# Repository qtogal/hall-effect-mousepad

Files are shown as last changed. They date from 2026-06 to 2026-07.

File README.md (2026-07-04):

Readme for the halleffectmousepad project.

This project aims to create a mousepad that includes a grid of hall effect sensors to detect magnets. The values of each will be interpreted by a program to calculate the position of the magnet even if it is not on the exact position of a sensor. 

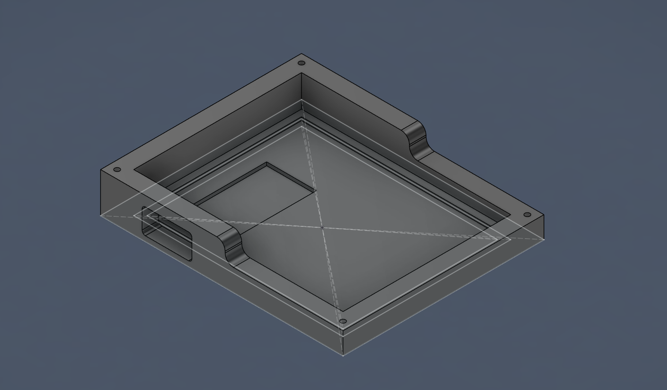
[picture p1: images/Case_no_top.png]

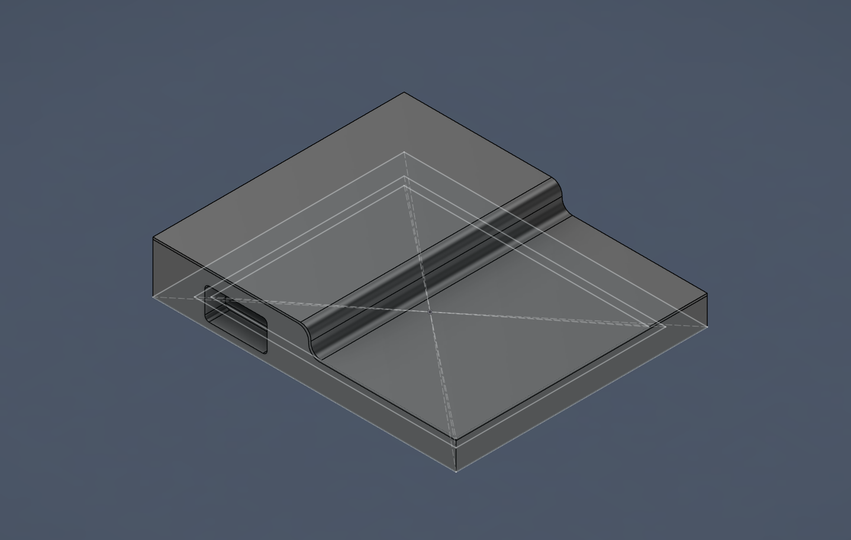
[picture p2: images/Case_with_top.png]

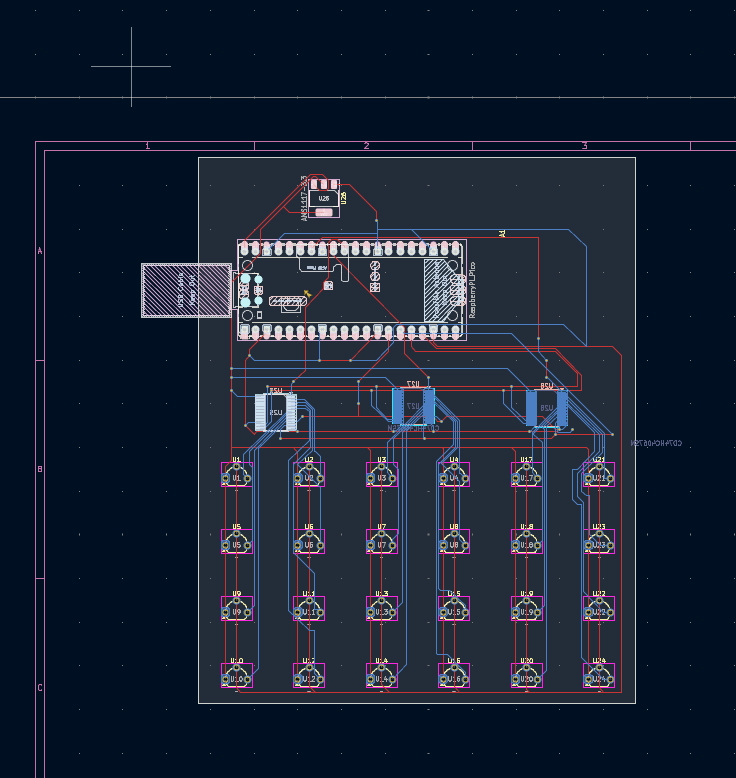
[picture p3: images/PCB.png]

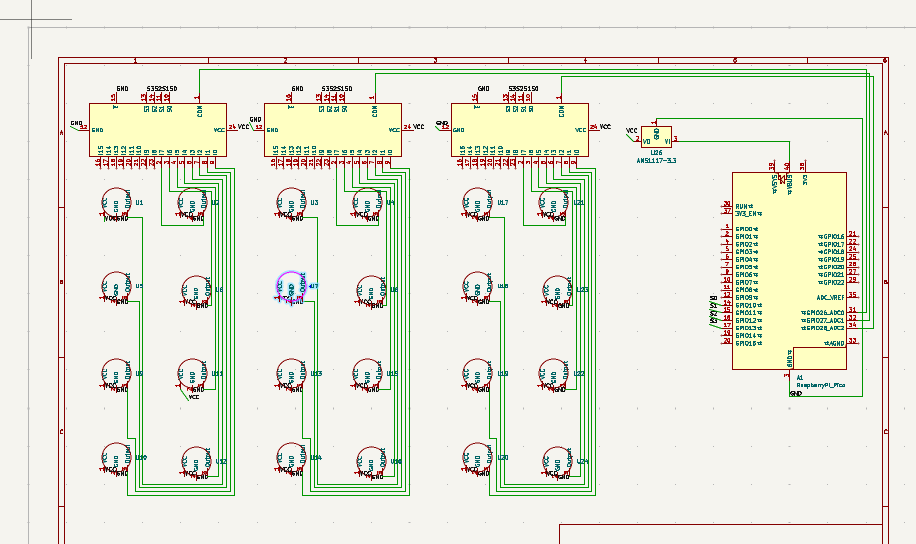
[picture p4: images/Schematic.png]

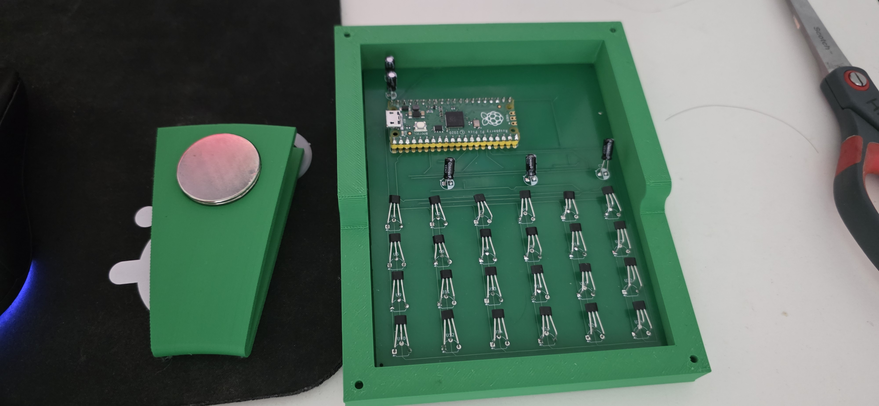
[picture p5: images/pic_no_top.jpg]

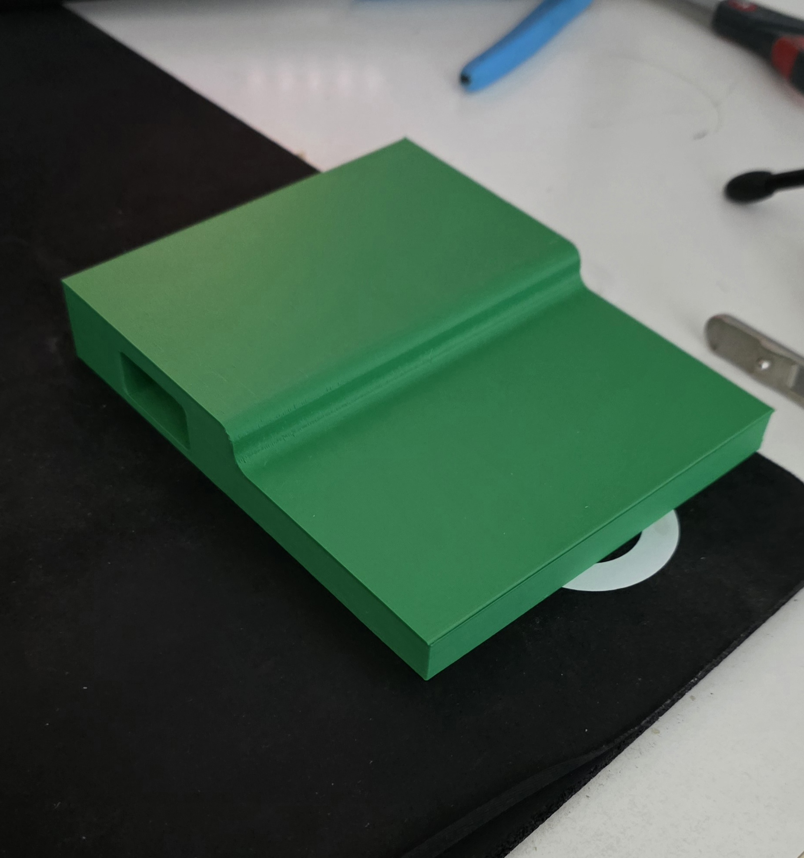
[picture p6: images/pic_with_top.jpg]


# BOM
 |Part|QTY|
 |---|---|
 |SS49E Hall Effect Sensor|24|
 |CD74HC4067SE analog mux|3|
 |AMS1117-3.3 regulator|1|
 |Neodyum magnets 12mm diameter*2mm|1|
 |0.1 uF capacitor|3|
 |10uF capacitor|2|
 |3D printed case|1|
 |3D printed magnet casing|1|
 |usb cable|1|

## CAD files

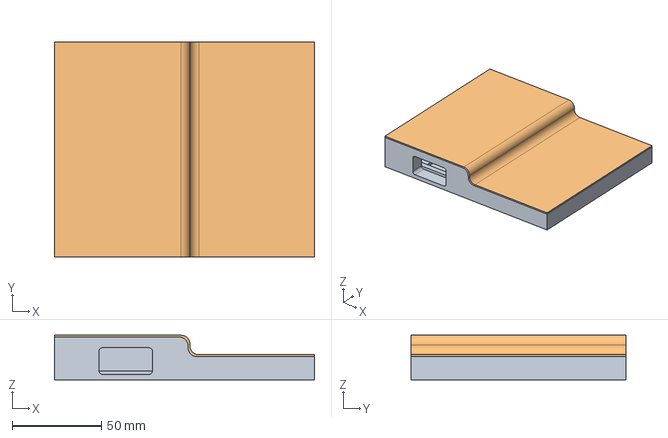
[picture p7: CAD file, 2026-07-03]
CAD/mousepad_.step
146.0 x 121.0 x 25.0 mm
コンポーネント1
コンポーネント3

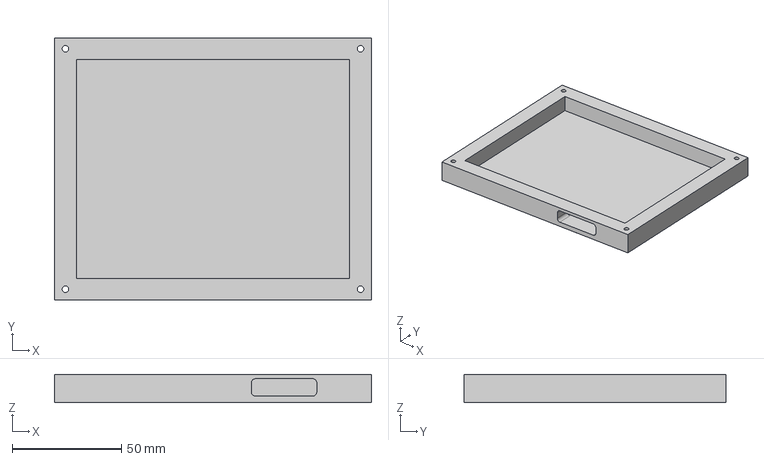
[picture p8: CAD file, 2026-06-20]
Production/Bottom.step
145.0 x 120.0 x 13.0 mm

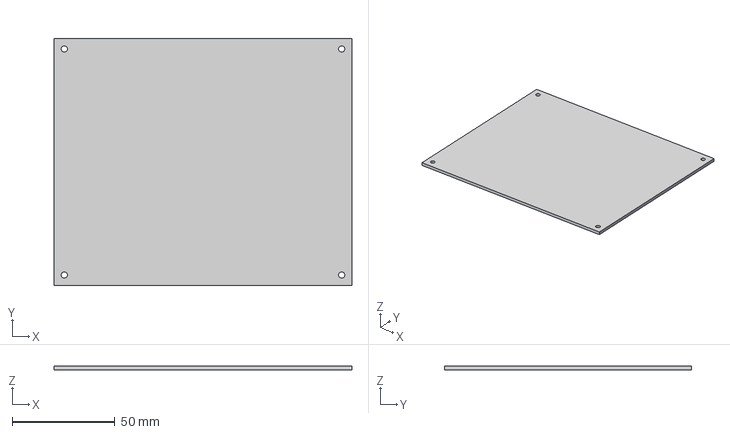
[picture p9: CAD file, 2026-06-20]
Production/top.step
145.0 x 120.0 x 2.00 mm

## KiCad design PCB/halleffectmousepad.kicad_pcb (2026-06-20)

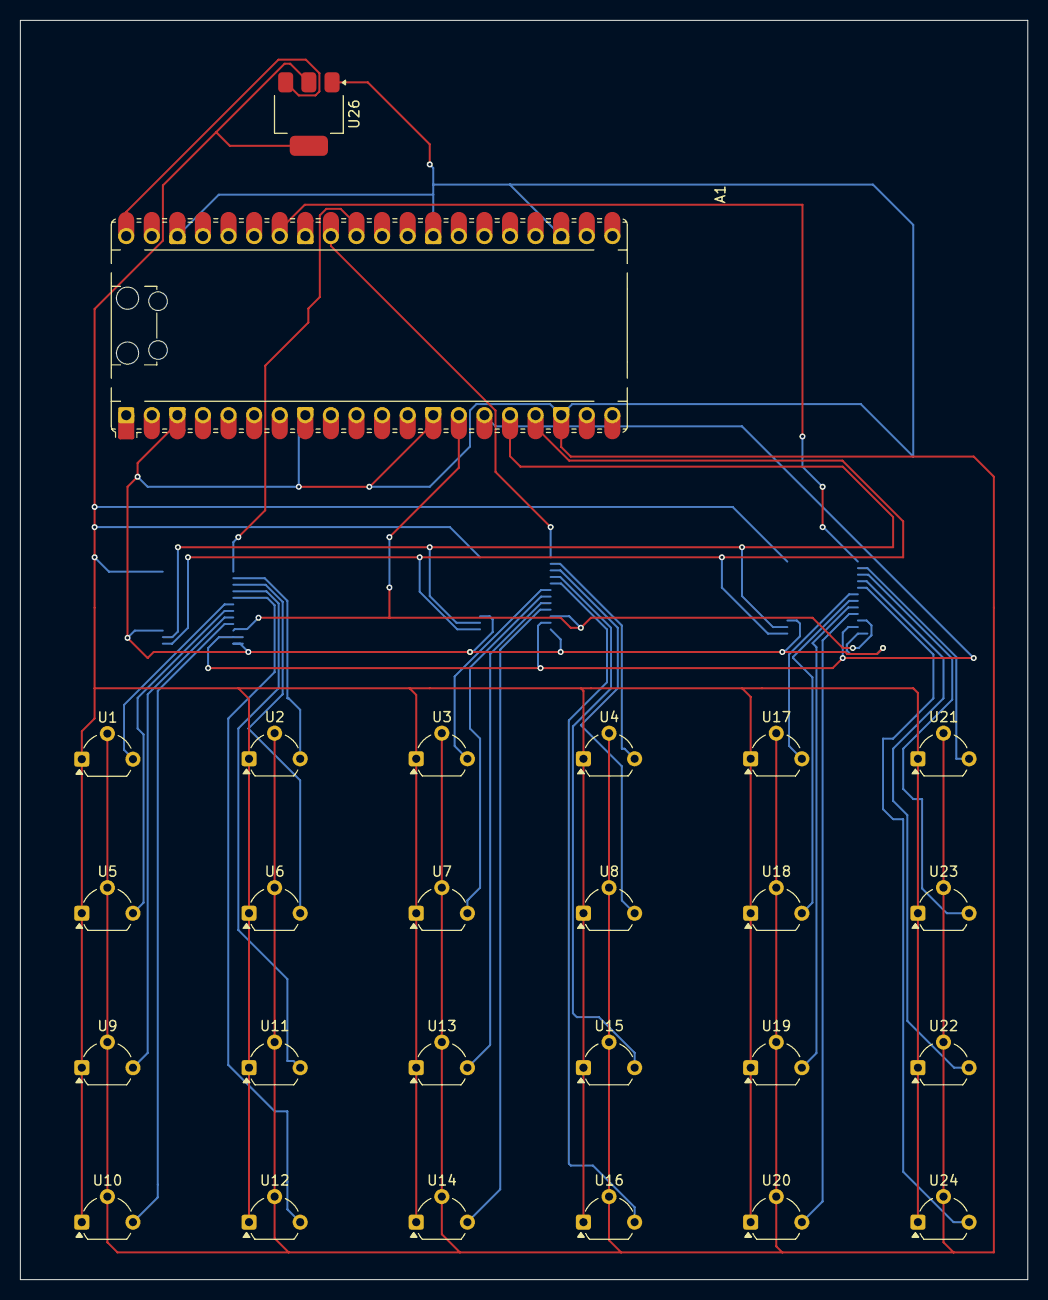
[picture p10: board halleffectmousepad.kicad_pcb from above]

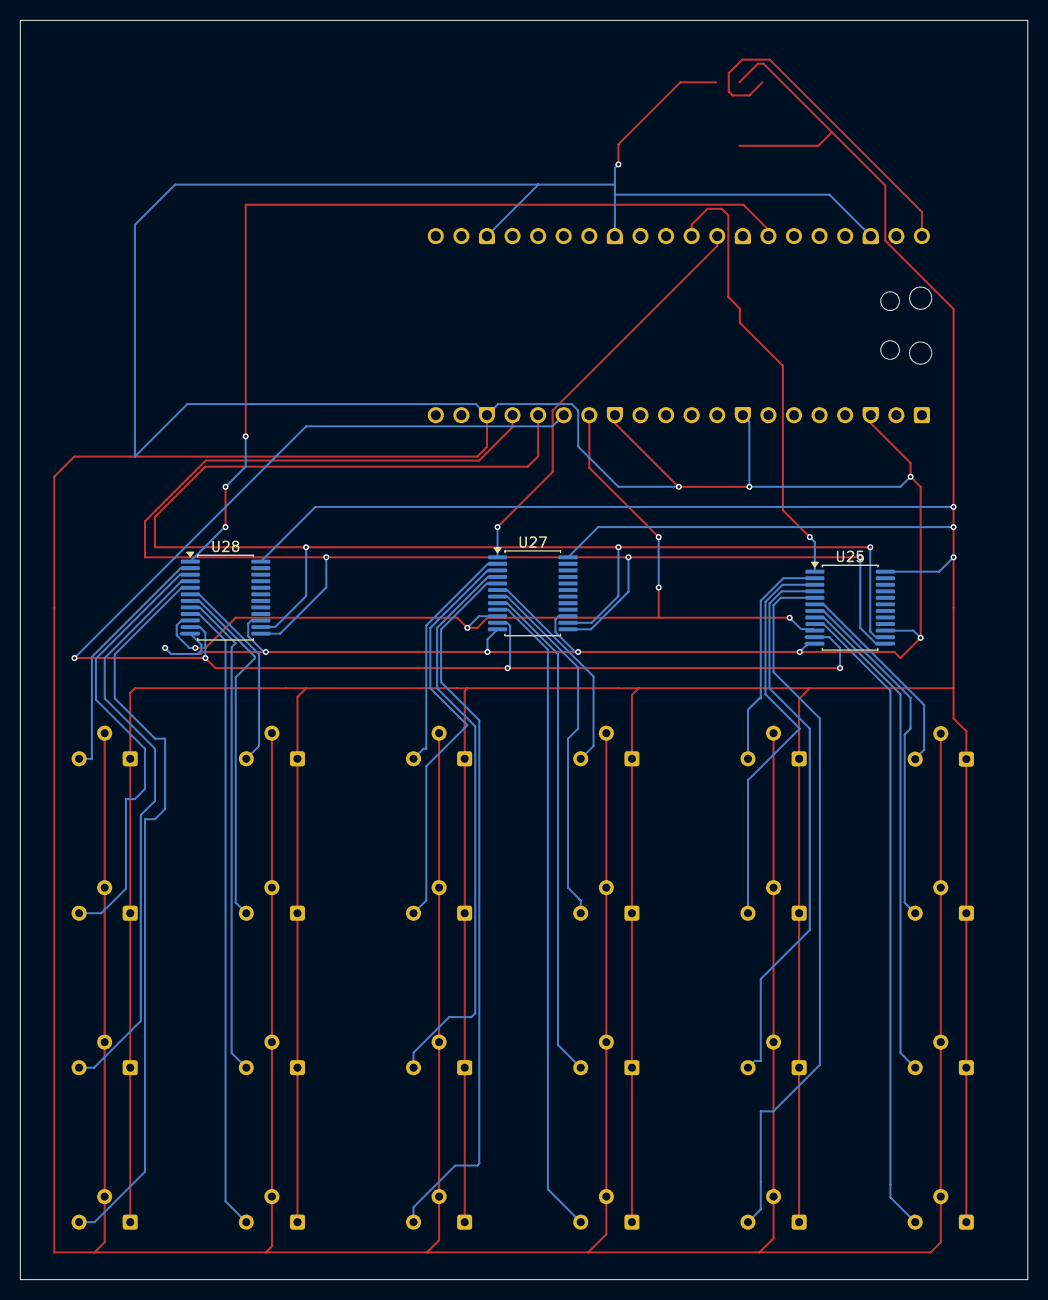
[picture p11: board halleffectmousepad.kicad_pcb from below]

Board: 2 copper layers, 100.0 x 125.0 mm, 29 parts (3 on the bottom side), 34 nets.

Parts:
A1: RaspberryPi_Pico; RaspberryPi_Pico_Common_Unspecified
U1, U2, U3, U4, U5, U6, U7, U8, U9, U10, U11, U12, U13, U14, U15, U16, U17, U18, U19, U20, U21, U22, U23, U24: TO-92L_Wide
U25, U27, U28: CD74HC4067SM; SSOP-24_5.3x8.2mm_P0.65mm
U26: AMS1117-3.3; SOT-223-3_TabPin2

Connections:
/GND: A1.3 (GND), A1.8 (GND), A1.13 (GND), A1.18 (GND), A1.23 (GND), A1.28 (GND), A1.38 (GND), U1.2 (GND), U2.2 (GND), U3.2 (GND), U4.2 (GND), U5.2 (GND), U6.2 (GND), U7.2 (GND), U8.2 (GND), U9.2 (GND), U10.2 (GND), U11.2 (GND), U12.2 (GND), U13.2 (GND), U14.2 (GND), U15.2 (GND), U16.2 (GND), U17.2 (GND), U18.2 (GND), U19.2 (GND), U20.2 (GND), U21.2 (GND), U22.2 (GND), U23.2 (GND), U24.2 (GND), U25.12 (GND), U25.15 (~E), U26.1 (GND), U27.12 (GND), U27.15 (~E), U28.12 (GND), U28.15 (~E)
/S0: A1.14 (GPIO10), U25.10 (S0), U27.10 (S0), U28.10 (S0)
/S1: A1.15 (GPIO11), U25.11 (S1), U27.11 (S1), U28.11 (S1)
/S2: A1.16 (GPIO12), U25.14 (S2), U27.14 (S2), U28.14 (S2)
/S3: A1.17 (GPIO13), U25.13 (S3), U27.13 (S3), U28.13 (S3)
/VCC: U1.1 (VCC), U2.1 (VCC), U3.1 (VCC), U4.1 (VCC), U5.1 (VCC), U6.1 (VCC), U7.1 (VCC), U8.1 (VCC), U9.1 (VCC), U10.1 (VCC), U11.1 (VCC), U12.1 (VCC), U13.1 (VCC), U14.1 (VCC), U15.1 (VCC), U16.1 (VCC), U17.1 (VCC), U18.1 (VCC), U19.1 (VCC), U20.1 (VCC), U21.1 (VCC), U22.1 (VCC), U23.1 (VCC), U24.1 (VCC), U25.24 (VCC), U26.2 (VO), U27.24 (VCC), U28.24 (VCC)
unnamed: A1.31 (GPIO26_ADC0), U25.1 (COM)
unnamed: A1.32 (GPIO27_ADC1), U27.1 (COM)
unnamed: A1.34 (GPIO28_ADC2), U28.1 (COM)
unnamed: A1.40 (VBUS), U26.3 (VI)
unnamed: U1.3 (Output), U25.6 (I3)
unnamed: U2.3 (Output), U25.2 (I7)
unnamed: U10.3 (Output), U25.9 (I0)
unnamed: U11.3 (Output), U25.4 (I5)
unnamed: U12.3 (Output), U25.5 (I4)
unnamed: U13.3 (Output), U27.8 (I1)
unnamed: U14.3 (Output), U27.9 (I0)
unnamed: U15.3 (Output), U27.4 (I5)
unnamed: U16.3 (Output), U27.5 (I4)
unnamed: U17.3 (Output), U28.6 (I3)
unnamed: U18.3 (Output), U28.7 (I2)
unnamed: U19.3 (Output), U28.8 (I1)
unnamed: U20.3 (Output), U28.9 (I0)
unnamed: U21.3 (Output), U28.2 (I7)
unnamed: U22.3 (Output), U28.4 (I5)
unnamed: U23.3 (Output), U28.3 (I6)
unnamed: U24.3 (Output), U28.5 (I4)
unnamed: U9.3 (Output), U25.8 (I1)
unnamed: U5.3 (Output), U25.7 (I2)
unnamed: U6.3 (Output), U25.3 (I6)
unnamed: U7.3 (Output), U27.7 (I2)
unnamed: U3.3 (Output), U27.6 (I3)
unnamed: U8.3 (Output), U27.3 (I6)
unnamed: U4.3 (Output), U27.2 (I7)

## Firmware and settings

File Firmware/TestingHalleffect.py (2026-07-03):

import time
import board
import analogio
import digitalio
import usb_hid
from adafruit_hid.mouse import Mouse

COLS = 6
ROWS = 4
MUX = 3
row_spacing = 16.6
col_spacing = 15.3

N = COLS*ROWS

select = []

for i in (board.GP10, board.GP11, board.GP12, board.GP13):
    pin = digitalio.DigitalInOut(i)
    pin.direction = digitalio.Direction.OUTPUT
    select.append(pin)

adc = [
    analogio.AnalogIn(board.A0),
    analogio.AnalogIn(board.A1),
    analogio.AnalogIn(board.A2),
]

mouse = Mouse(usb_hid.devices)

#Make the mapping of the sensor layout based on the pins connected to each sensor, (ch, x, y)
mux0_sensor_map = [
    (0,0,3), (1,0,2), (2,0,1), (3,0,0), (4,1,3), (5,1,2), (6,1,1), (7,1,0)
]

mux1_sensor_map = [
    (0,2,3), (1,2,2), (2,2,1), (3,2,0), (4,3,3), (5,3,2), (6,3,1), (7,3,0)
]

mux2_sensor_map = [
    (0,4,3), (1,4,2), (2,4,1), (3,4,0), (4,5,3), (5,5,2), (6,5,1), (7,5,0)
]

mux_map = [mux0_sensor_map, mux1_sensor_map, mux2_sensor_map]

sensor_map = [
    [0,0,0,0,0,0,0,0],
    [0,0,0,0,0,0,0,0],
    [0,0,0,0,0,0,0,0],          
]

baseline_sensor = sensor_map

using_map = [
    [0,0,0,0,0,0,0,0],
    [0,0,0,0,0,0,0,0],
    [0,0,0,0,0,0,0,0],          
]

def set_channel(ch):
    for i, pin in enumerate(select):
        pin.value = bool((ch >>i )&1)

def read_all():
    for i in range(8):
        set_channel(i)
        sensor_map[mux0_sensor_map[i][2]][mux0_sensor_map[i][1]] = abs(adc[mux0_sensor_map[i][0]].value)
        sensor_map[mux1_sensor_map[i][2]][mux1_sensor_map[i][1]] = abs(adc[mux1_sensor_map[i][0]].value)
        sensor_map[mux2_sensor_map[i][2]][mux2_sensor_map[i][1]] = abs(adc[mux2_sensor_map[i][0]].value)
    
#actual code for mouse detection

#constants
noise = 300                             # per sensor adc count jitter range
lift = 3000                             # adc value maximum before considering lifted
dpi = 20                                # scaling movement distance
wait = 0.001                            # delay set for mux to settle
calibration_frames = 20                 # initial sensor calibration frames
smooth = 0.5                            # fraction of change in x and y recorded as movement
delay = 0.25
click_ratio = 1.5

# Calibrate sensor readings by taking an average over 20 frames

for _ in range(calibration_frames):
    read_all()
    for i in range(MUX):
        for j in range(N/MUX):
            baseline_sensor[i][j] += sensor_map[i][j]
    
for i in range(MUX):
    for j in range(N/MUX):
        baseline_sensor[i][j]/calibration_frames

prev_cx = None       # previous frame position
prev_cy = None
smooth_cx = None     # low-pass-filtered cursor position
smooth_cy = None
rem_x = 0.0          # carry sub-pixel remainders
rem_y = 0.0
click_top_threshold = 5000    # click when reading a value above this
click_bot_threshold = 4000    # unclick when reading a value below this
clicking = False     # if button is pressed
settle_until = 0.0   # clicks don't activate until this time after the magnet lands

while True:
    now = time.monotonic()
    sx = 0.0
    sy = 0.0
    total = 0
    peak = 0

    read_all()
    for i in range(MUX):
        for j in range(N/MUX):
            w = sensor_map[i][j] - baseline_sensor[i][j]
            if w>noise:
                x = mux_map[i][j][2]
                y = mux_map[i][j][3]
                sx += w*x
                sy += w*y
                total += w
                if w> peak: 
                    peak = w
    if total > LIFT:   #weighted average
        cx = sx/total
        cy = sy/total
        if smooth_cx is None:  #record cx and cy as smooth_cx and smooth_cy if they don't have any values stored
            smooth_cx = cx
            smooth_cy = cy
        else:
            smooth_cx += (cx - smooth_cx)*smooth
            smooth_cy += (cy - smooth_cy)*smooth
        if prev_cx is None:   #No previous position is recorded
            prev_cx = smooth_cx
            prev_cy = smooth_cy
            rem_x = 0.0
            rem_y = 0.0
        else:
            dx = (smooth_cx - prev_cx)*dpi + rem_x
            dy = (smooth_cy - prev_cy)*dpi + rem_y
            ix = int(dx)
            iy = int(dy)
            rem_x = dx - ix
            rem_y = dy - iy
            if ix != 0 or iy != 0:
                mouse.move(x=ix, y=iy)
            prev_cx = smooth_cx
            prev_cy = smooth_cy

        if not clicking:
            if peak>click_top_threshold:
                mouse.press(Mouse.LEFT_BUTTON)
                clicking = True
        else: 
            if peak < click_bot_threshold:
                mouse.release(Mouse.LEFT_BUTTON)
                clicking = False

    else:
        prev_cx = None       
        prev_cy = None
        smooth_cx = None     
        smooth_cy = None
        hover_peak = None  






    
